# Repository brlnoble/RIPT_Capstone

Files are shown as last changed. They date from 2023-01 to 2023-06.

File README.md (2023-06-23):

# R.I.P.T. Capstone Project
This is a final year engineering capstone project for McMaster University. Students were given 8 months to develop a project and then present to judges and supervisors.

🏅3rd place for Most Impressive Prototype.

___

## About the Project
The **Robot Integrated Pad Trainer** (R.I.P.T.) is a device for helping boxers develop their offensive skills. The project uses a YOLOv7 computer vision model to observe and track the user with webcams, and identifies deficiencies in their skills. Once a training regime has been developed by a custom algorithm, pad training sessions can be conducted with the new regime. A gantry like system moves pads around for the user to interact with, sensing when they are hit before moving to a new location. This robotic emulation of a human pad trainer allows for more direct customization in the training, and is expandable and repeatable for any number of users and skill levels.

This project is a collaboration between Brandon Noble ([brlnoble](https://github.com/brlnoble "Brandon's Github")), Labib Kazi ([kazia3](https://github.com/kazia3 "Labib's Github")), Jame Tran ([JameTran](https://github.com/JameTran "Jame's Github")), and Hunter Ceranic ([cer-hunter](https://github.com/cer-hunter "Hunter's Github")).

### Explanation and Demonstration
View the explanation on YouTube <a href="https://youtu.be/TRa0bQ9WmGY" target="_blank" rel="noopener noreferrer">here</a>

View the demonstration on YouTube <a href="https://youtu.be/QMfrOVIuLZo" target="_blank" rel="noopener noreferrer">here</a>

___

## Project Goals
- [X] Robotic system to control boxing training pads
  - [X] H-bot inspired pulley system with 10mm GT2 belt, and custom mounts
  - [X] Zero motor position
  - [X] Fine motor control for NEMA 24 stepper motors to accurately move gantry system to specific locations
- [X] System to change pad orientation along 2 axes
  - [X] Mechanical design to support pad
  - [X] Control over position for different types of punches
- [X] YOLOv7 computer vision model
  - [X] Train YOLOv7 tiny model to recognize faces and boxing gloves
  - [X] Deploy on NVIDIA Jetson Nano
  - [X] Determine user blocking with intersection between gloves and face
- [X] Display and collect user metrics
  - [X] Implement various sensors to collect user metrics (i.e. reaction time, speed, endurance, accuracy, etc.)
  - [X] Web application to display metrics and training sessions
  - [X] Utilize user metrics to personalize a training regime
  
___

## Current State
The project is completed and almost all of the original goals have been met. Below are some pictures and GIFs of the device in operation.

#### Operation of the Device



#### 3D Model of the Future of RIPT
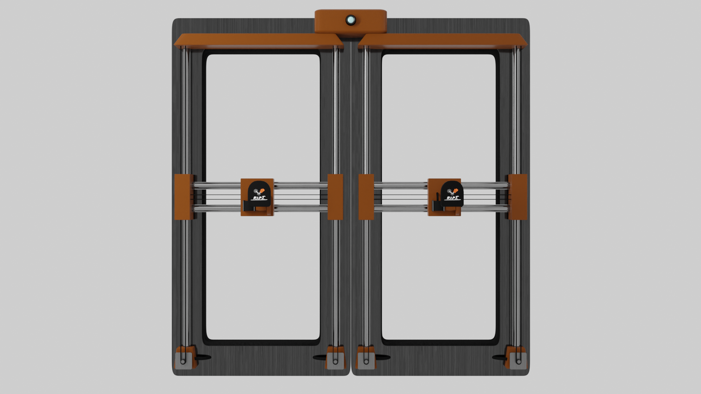
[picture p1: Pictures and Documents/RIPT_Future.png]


### Front End Demonstration of the Web App
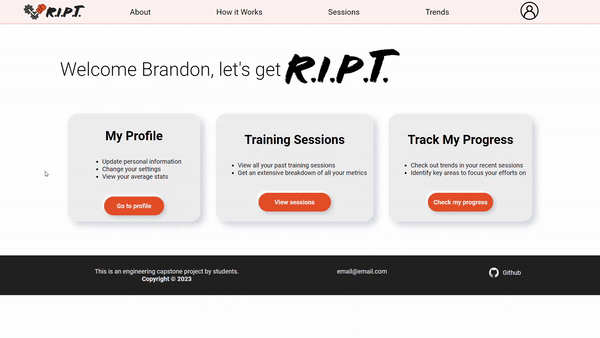
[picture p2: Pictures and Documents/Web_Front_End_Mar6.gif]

You can view a function version of the website at https://brlnoble.github.io/RIPT_Capstone/

#### Demonstration of the YOLOv7 Model
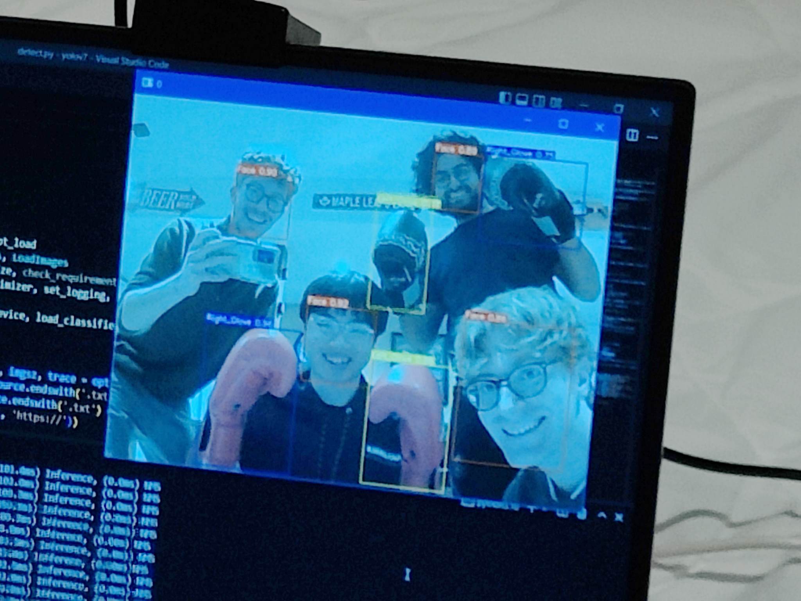
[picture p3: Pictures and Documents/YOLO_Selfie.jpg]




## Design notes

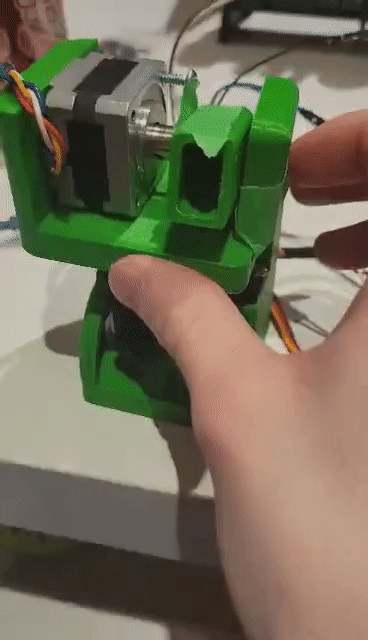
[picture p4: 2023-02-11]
Pictures and Documents/Pad_Orient_1.gif

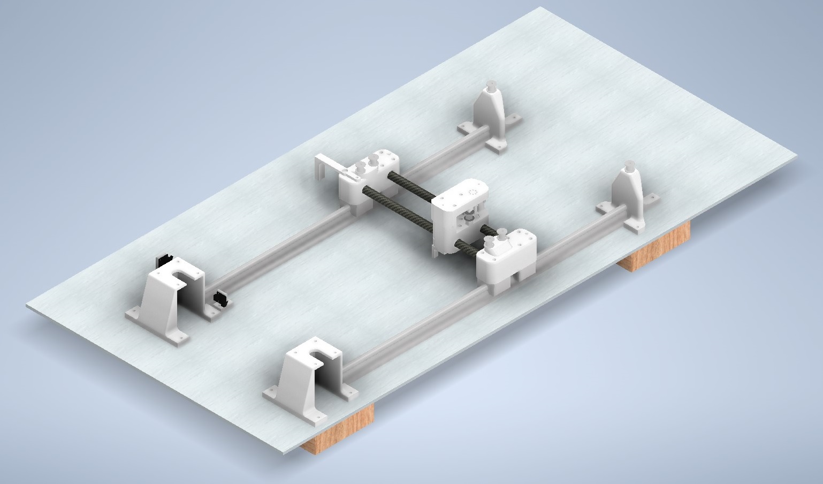
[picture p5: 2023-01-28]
Pictures and Documents/One_Side_Model.jpg

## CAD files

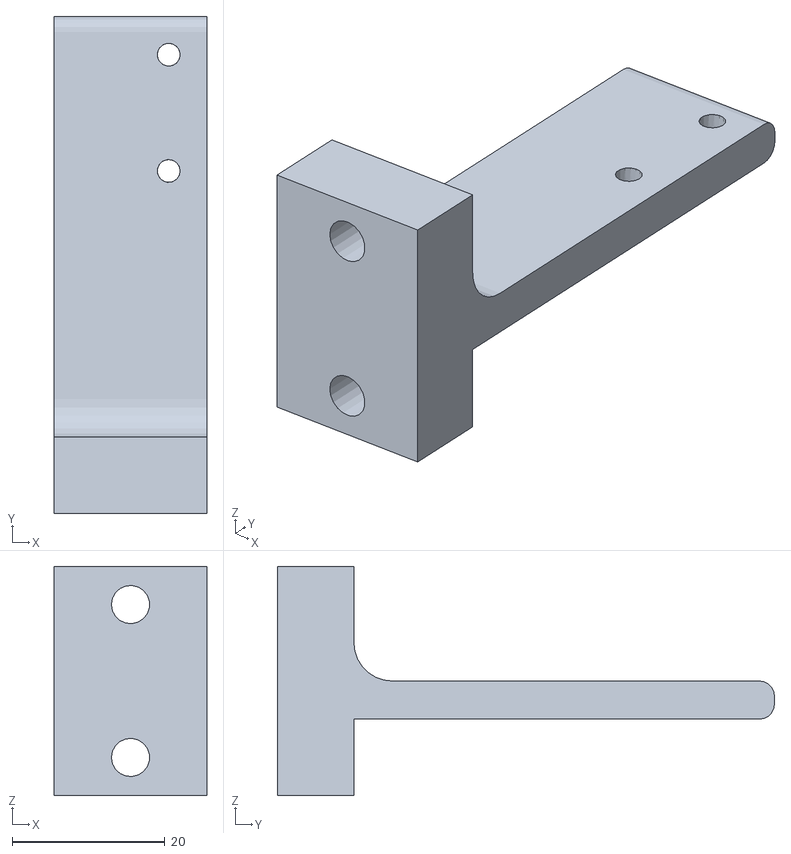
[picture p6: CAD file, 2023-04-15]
CAD Designs/Zero - Y Switch.stl
20.0 x 65.0 x 30.0

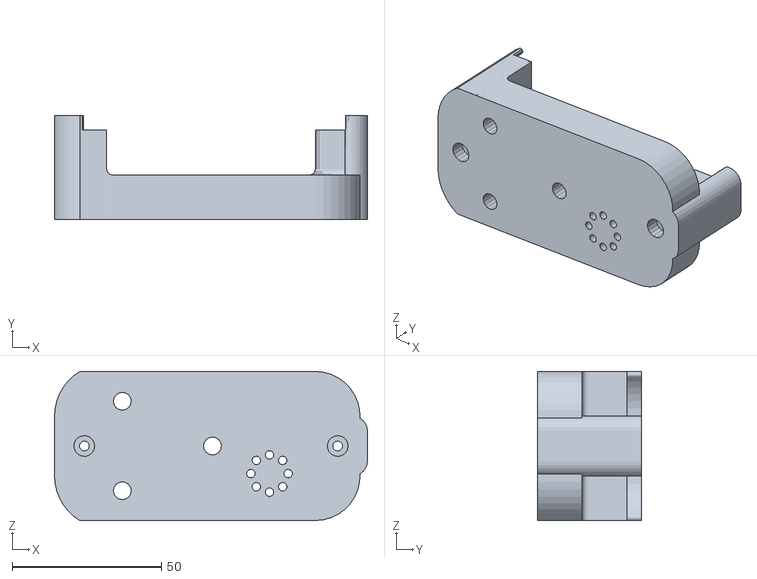
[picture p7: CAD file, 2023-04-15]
CAD Designs/Slider - Top.stl
105.0 x 35.0 x 50.0

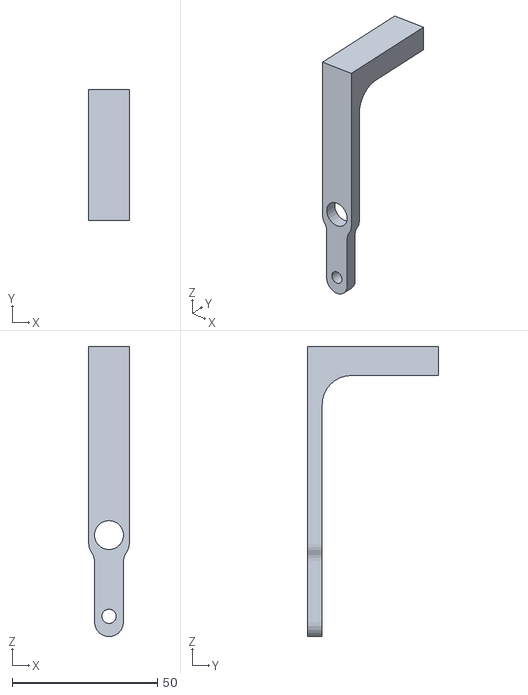
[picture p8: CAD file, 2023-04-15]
CAD Designs/Zero - Y Bracket.stl
14.0 x 45.0 x 99.9

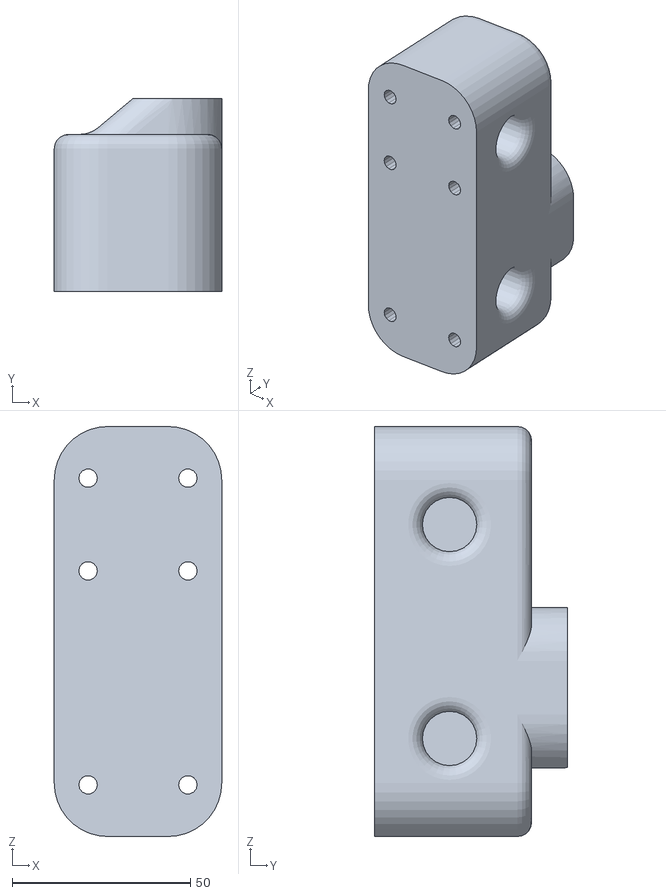
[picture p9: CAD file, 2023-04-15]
CAD Designs/Carbon Rod Mount R.stl
47.0 x 54.0 x 115.0

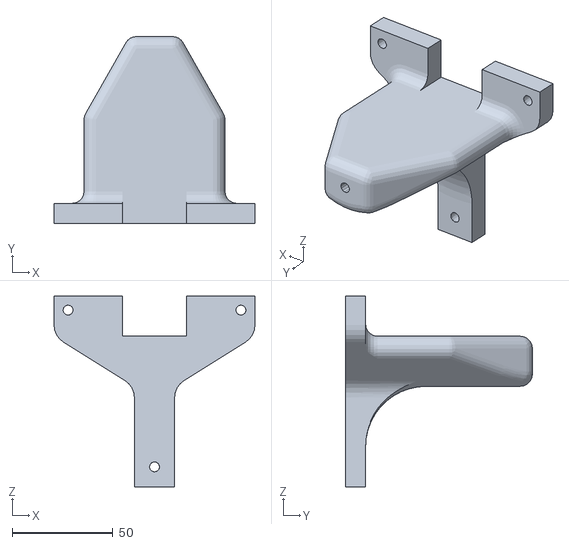
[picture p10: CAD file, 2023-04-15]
CAD Designs/Idler Mount.stl
100.0 x 93.0 x 95.0

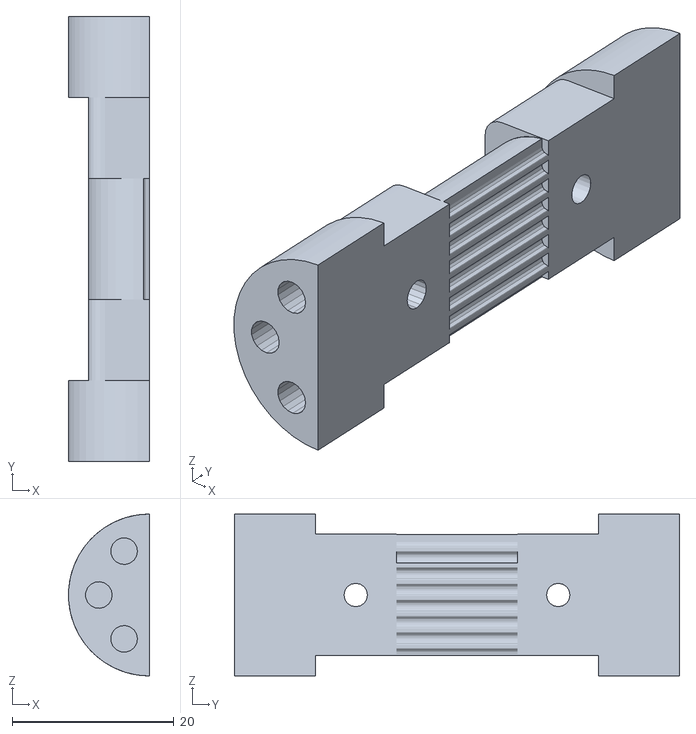
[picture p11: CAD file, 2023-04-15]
CAD Designs/Spool - Toothed Circle 2.stl
9.98 x 55.0 x 20.0

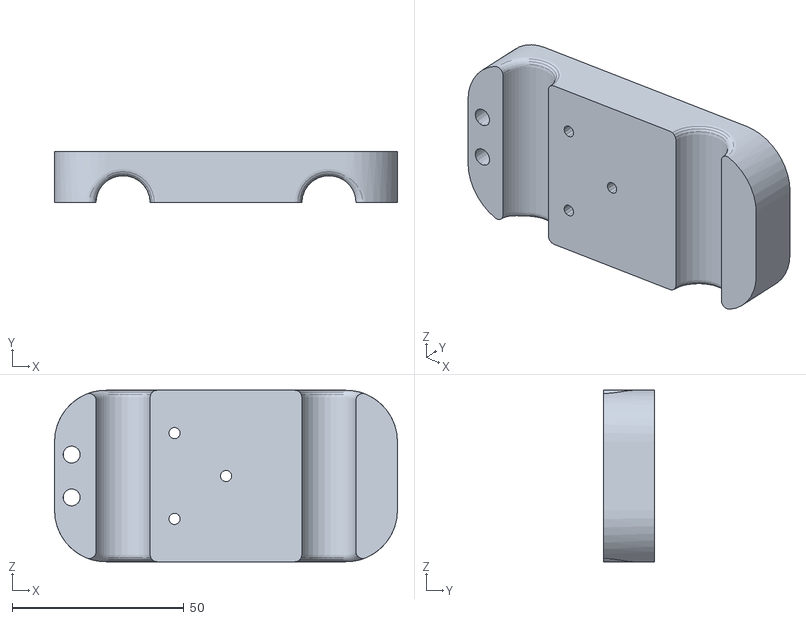
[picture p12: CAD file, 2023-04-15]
CAD Designs/Slider - Bottom.stl
100.0 x 15.0 x 50.0

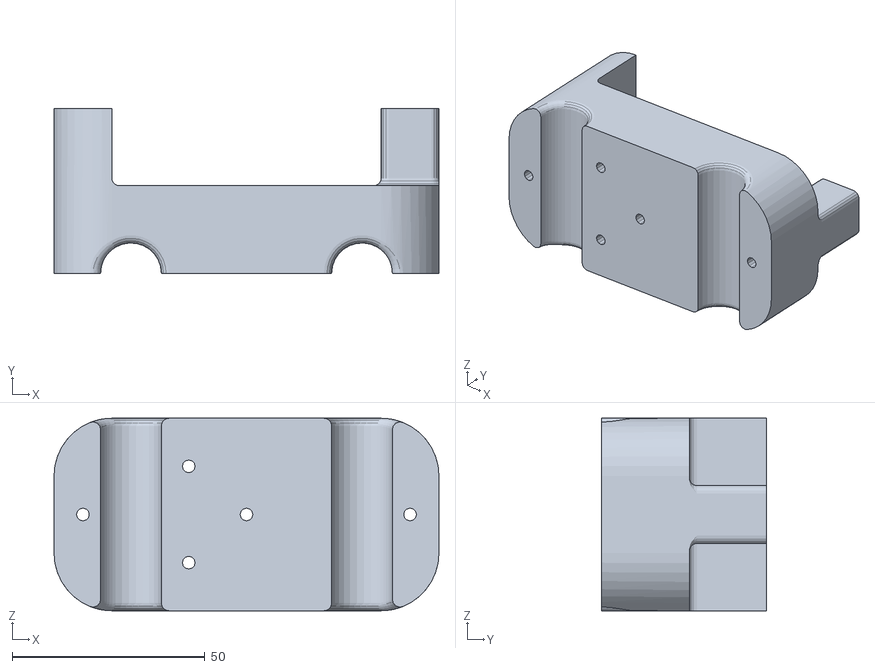
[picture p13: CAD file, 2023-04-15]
CAD Designs/Slider - Centre.stl
100.0 x 42.8 x 50.0

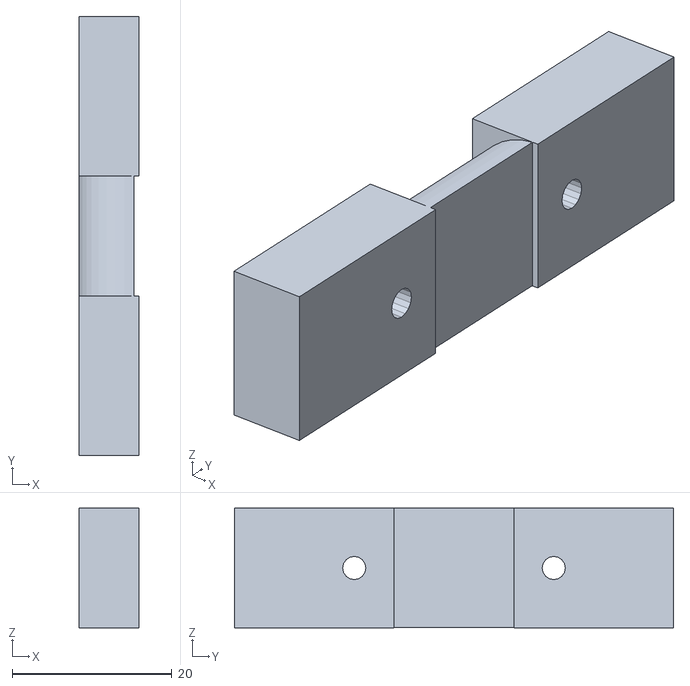
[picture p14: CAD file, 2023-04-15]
CAD Designs/Spool - Flat Square 2.stl
7.50 x 55.0 x 15.0

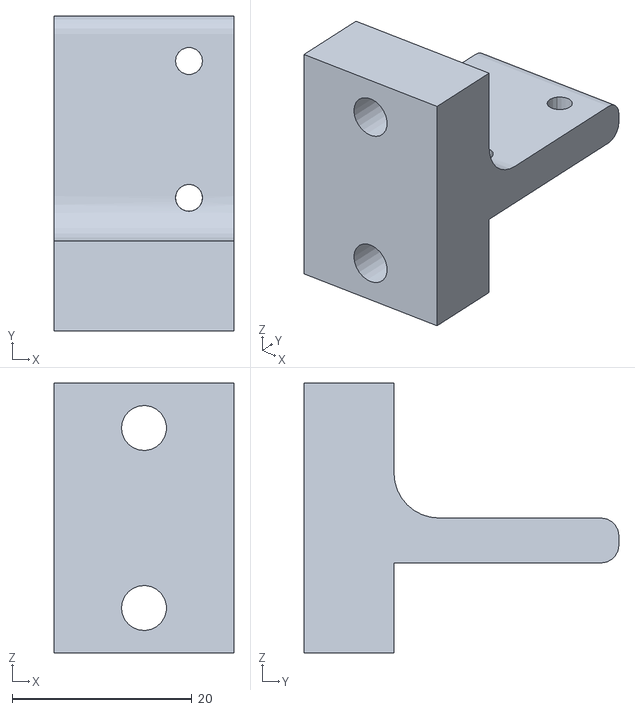
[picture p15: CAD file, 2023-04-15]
CAD Designs/Zero - X Switch.stl
20.0 x 35.0 x 30.0

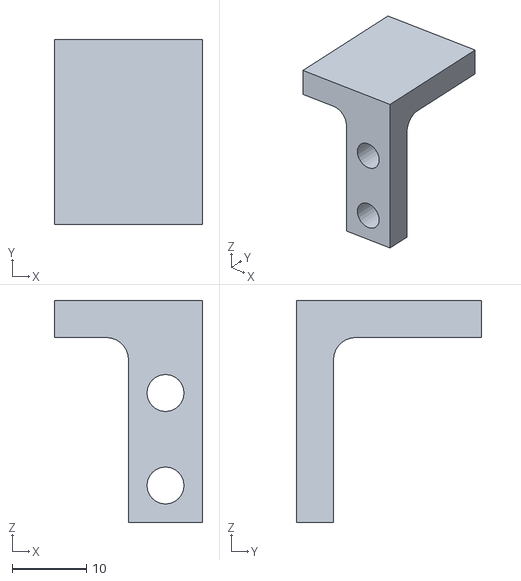
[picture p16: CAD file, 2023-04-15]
CAD Designs/Zero - X Bracket.stl
20.0 x 25.0 x 30.0

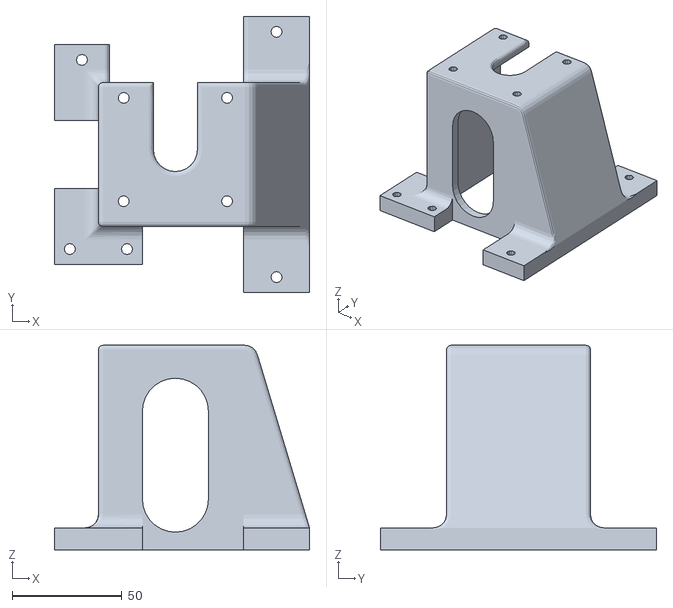
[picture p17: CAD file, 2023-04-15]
CAD Designs/Nema Mount.stl
116.0 x 125.5 x 93.0

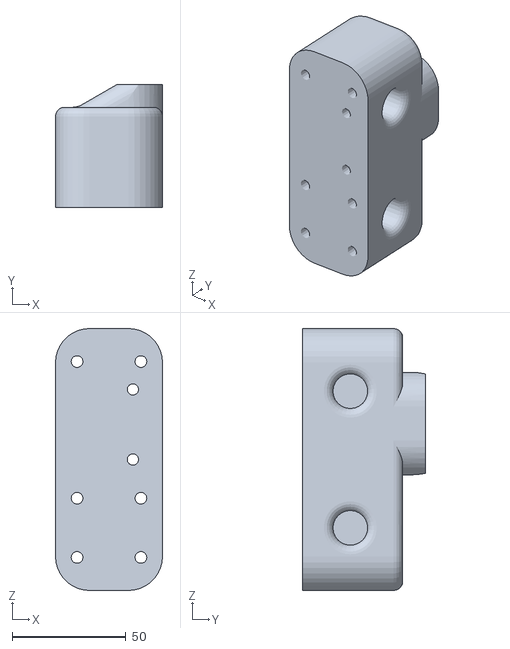
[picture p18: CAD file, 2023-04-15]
CAD Designs/Carbon Rod Mount L.stl
47.0 x 54.0 x 115.0

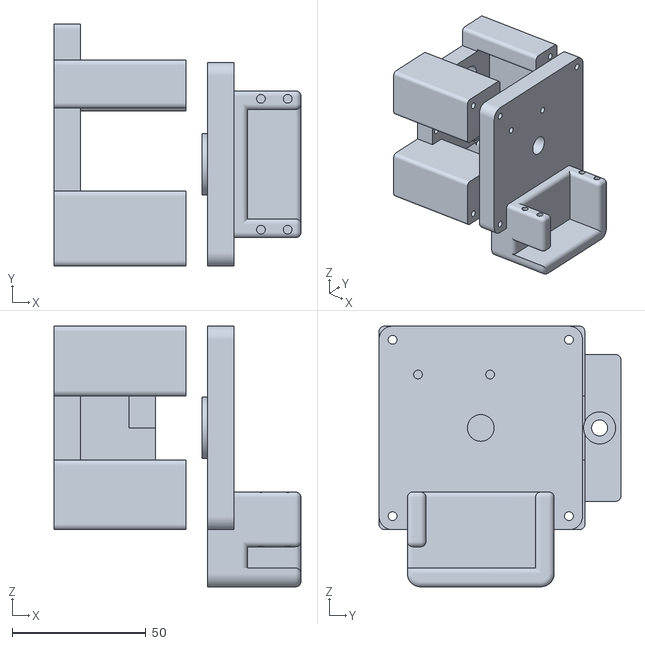
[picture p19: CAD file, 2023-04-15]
CAD Designs/padmount_doubleservo.stl
92.5 x 90.6 x 97.6

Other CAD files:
CAD Designs/Spool - Flat Circle 2.stl
CAD Designs/Spool - Toothed Square.stl
CAD Designs/finger.stl
CAD Designs/separator_plate_alternate.stl
CAD Designs/Slider Top 2.stl
CAD Designs/finger.ipt
CAD Designs/padmount_doubleservo.iam
CAD Designs/separator_plate_alternate.ipt
CAD Designs/servo_horz_plate.ipt
CAD Designs/servo_horz_plate.stl
CAD Designs/servo_pressfit_plate.ipt
CAD Designs/servo_pressfit_plate.stl
CAD Designs/stick_mount.ipt
CAD Designs/stick_mount.stl

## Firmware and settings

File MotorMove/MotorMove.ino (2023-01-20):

// Define stepper motor connections:
#define dirPin1 2
#define stepPin1 3

#define dirPin2 6
#define stepPin2 11

// Define limit switches
#define xLimit 9
#define yLimit 10


void setup() {
  pinMode(stepPin1, OUTPUT);
  pinMode(dirPin1, OUTPUT);

  pinMode(stepPin2, OUTPUT);
  pinMode(dirPin2, OUTPUT);
}

// ~~~~~~~~~~~~~~~~~~~~~~~~~~~~~~~~~~~~~~~~~~~~~
// ~~~~~~~~~~~~~~~~~~~~~~~~~~~~~~~~~~~~~~~~~~~~~
// ~~~~~~~~~~~~~~~~~~~~~~~~~~~~~~~~~~~~~~~~~~~~~
// ~~~~~~~~~~~~~~~~~~~~~~~~~~~~~~~~~~~~~~~~~~~~~

bool run = true;

//loop currently contains test code to find max frequency
void loop() {
  // put your main code here, to run repeatedly:
  if(run) {
    int numStepsX = 500;
    int numStepsY = 2000;
    int microdel = 230;
    int del = 40;
    digitalWrite(dirPin1,1);
    digitalWrite(dirPin2,0);

    for(int i=0;i<numStepsY;i++) {
      digitalWrite(stepPin1, HIGH);
      digitalWrite(stepPin2, HIGH);
      delayMicroseconds(microdel);
      digitalWrite(stepPin1, LOW);
      digitalWrite(stepPin2, LOW);
      delayMicroseconds(microdel);
    }

    delay(del);

    digitalWrite(dirPin1,1);
    digitalWrite(dirPin2,1);

    for(int i=0;i<numStepsX;i++) {
      digitalWrite(stepPin1, HIGH);
      digitalWrite(stepPin2, HIGH);
      delayMicroseconds(microdel);
      digitalWrite(stepPin1, LOW);
      digitalWrite(stepPin2, LOW);
      delayMicroseconds(microdel);
    }

    delay(del);

    digitalWrite(dirPin1,0);
    digitalWrite(dirPin2,1);

    for(int i=0;i<numStepsY;i++) {
      digitalWrite(stepPin1, HIGH);
      digitalWrite(stepPin2, HIGH);
      delayMicroseconds(microdel);
      digitalWrite(stepPin1, LOW);
      digitalWrite(stepPin2, LOW);
      delayMicroseconds(microdel);
    }

    delay(del);

    digitalWrite(dirPin1,0);
    digitalWrite(dirPin2,0);

    for(int i=0;i<numStepsX;i++) {
      digitalWrite(stepPin1, HIGH);
      digitalWrite(stepPin2, HIGH);
      delayMicroseconds(microdel);
      digitalWrite(stepPin1, LOW);
      digitalWrite(stepPin2, LOW);
      delayMicroseconds(microdel);
    }
    
    delay(del);
    run = false;
  }
  
}
// ~~~~~~~~~~~~~~~~~~~~~~~~~~~~~~~~~~~~~~~~~~~~~
// ~~~~~~~~~~~~~~~~~~~~~~~~~~~~~~~~~~~~~~~~~~~~~
// ~~~~~~~~~~~~~~~~~~~~~~~~~~~~~~~~~~~~~~~~~~~~~
// ~~~~~~~~~~~~~~~~~~~~~~~~~~~~~~~~~~~~~~~~~~~~~

// ~~~~~ Converts cm to motor steps ~~~~~
int distToStep(float cm) {
  return int(cm*0.009);
}

// ~~~~~~~~~~~~~~~~~~~~~~~~~~~~~~~~~~~~~~~~~~~~~
// ~~~~~~~~~~~~~~~~~~~~~~~~~~~~~~~~~~~~~~~~~~~~~
// ~~~~~ Move Y ~~~~~
void moveY(float currPos, float newPos) {
  float vector = currPos - newPos; //Calculates Y vector

  //Specifies up or down
  int direction = ( abs(vector) - vector) / abs(2*vector);
  digitalWrite(dirPin1, direction);
  digitalWrite(dirPin2, ~direction);

  //Move the device
  int numSteps = distToStep(vector);
  for(int i=0;i<numSteps;i++) {
    digitalWrite(stepPin1, HIGH);
    digitalWrite(stepPin2, HIGH);
    delayMicroseconds(50);
    digitalWrite(stepPin1, LOW);
    digitalWrite(stepPin2, LOW);
    delayMicroseconds(50);
  }
}

// ~~~~~~~~~~~~~~~~~~~~~~~~~~~~~~~~~~~~~~~~~~~~~
// ~~~~~~~~~~~~~~~~~~~~~~~~~~~~~~~~~~~~~~~~~~~~~
// ~~~~~ Move X ~~~~~
void moveX(float currPos, float newPos) {
  float vector = currPos - newPos; //Calculates Y vector

  //Specifies left or right
  int direction = ( abs(vector) - vector) / abs(2*vector);
  digitalWrite(dirPin1, direction);
  digitalWrite(dirPin2, direction);

  //Move the device
  int numSteps = distToStep(vector);
  for(int i=0;i<numSteps;i++) {
    digitalWrite(stepPin1, HIGH);
    digitalWrite(stepPin2, HIGH);
    delayMicroseconds(50);
    digitalWrite(stepPin1, LOW);
    digitalWrite(stepPin2, LOW);
    delayMicroseconds(50);
  }
}


// ~~~~~~~~~~~~~~~~~~~~~~~~~~~~~~~~~~~~~~~~~~~~~
// ~~~~~~~~~~~~~~~~~~~~~~~~~~~~~~~~~~~~~~~~~~~~~
// ~~~~~ Zero the unit ~~~~~
void goToZero() {
  //Move slightly down first
  digitalWrite(dirPin1, 0);
  digitalWrite(dirPin2, 1);

  for(int i=0;i<100;i++) {
    digitalWrite(stepPin1, HIGH);
    digitalWrite(stepPin2, HIGH);
    delayMicroseconds(50);
    digitalWrite(stepPin1, LOW);
    digitalWrite(stepPin2, LOW);
    delayMicroseconds(50);
  }

  //Move slightly to the right
  digitalWrite(dirPin1, 0);
  digitalWrite(dirPin2, 0);

  for(int i=0;i<100;i++) {
    digitalWrite(stepPin1, HIGH);
    digitalWrite(stepPin2, HIGH);
    delayMicroseconds(50);
    digitalWrite(stepPin1, LOW);
    digitalWrite(stepPin2, LOW);
    delayMicroseconds(50);
  }

  //Move Y until it hits the switch
  digitalWrite(dirPin1, 1);
  digitalWrite(dirPin2, 0);

  while(digitalRead(yLimit) == 0) {
    digitalWrite(stepPin1, HIGH);
    digitalWrite(stepPin2, HIGH);
    delayMicroseconds(200);
    digitalWrite(stepPin1, LOW);
    digitalWrite(stepPin2, LOW);
    delayMicroseconds(200);    
  }

  //Move X until it hits the switch
  digitalWrite(dirPin1, 1);
  digitalWrite(dirPin2, 1);

  while(digitalRead(xLimit) == 0) {
    digitalWrite(stepPin1, HIGH);
    digitalWrite(stepPin2, HIGH);
    delayMicroseconds(200);
    digitalWrite(stepPin1, LOW);
    digitalWrite(stepPin2, LOW);
    delayMicroseconds(200);    
  }

  //Move slightly down
  digitalWrite(dirPin1, 0);
  digitalWrite(dirPin2, 1);

  for(int i=0;i<100;i++) {
    digitalWrite(stepPin1, HIGH);
    digitalWrite(stepPin2, HIGH);
    delayMicroseconds(500);
    digitalWrite(stepPin1, LOW);
    digitalWrite(stepPin2, LOW);
    delayMicroseconds(500);
  }

  //Move slightly to the right
  digitalWrite(dirPin1, 0);
  digitalWrite(dirPin2, 0);

  for(int i=0;i<100;i++) {
    digitalWrite(stepPin1, HIGH);
    digitalWrite(stepPin2, HIGH);
    delayMicroseconds(500);
    digitalWrite(stepPin1, LOW);
    digitalWrite(stepPin2, LOW);
    delayMicroseconds(500);
  }

  //Move up really slowly same distance as it was moved down in the last step
  digitalWrite(dirPin1, 1);
  digitalWrite(dirPin2, 0);

  for(int i=0;i<100;i++) {
    digitalWrite(stepPin1, HIGH);
    digitalWrite(stepPin2, HIGH);
    delayMicroseconds(500);
    digitalWrite(stepPin1, LOW);
    digitalWrite(stepPin2, LOW);
    delayMicroseconds(500);
  }

  //Move left really slowly same distance as it was moved right in the last step
  digitalWrite(dirPin1, 1);
  digitalWrite(dirPin2, 1);

  for(int i=0;i<100;i++) {
    digitalWrite(stepPin1, HIGH);
    digitalWrite(stepPin2, HIGH);
    delayMicroseconds(500);
    digitalWrite(stepPin1, LOW);
    digitalWrite(stepPin2, LOW);
    delayMicroseconds(500);
  }

  //restart calibration if the pad is not zeroed
  if(digitalRead(yLimit) == 0 || digitalRead(xLimit) == 0){
    goToZero();
  }
}

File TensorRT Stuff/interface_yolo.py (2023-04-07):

"""
An example that uses TensorRT's Python api to make inferences.
"""
import ctypes
import os
import shutil
import random
import sys
import threading
import time
import cv2
import numpy as np
import pycuda.autoinit
import pycuda.driver as cuda
import tensorrt as trt

#ADDED
import PySimpleGUI as sg
import sgInterface
import RPi.GPIO as GPIO
from time import perf_counter,sleep

from form_send import Client

CONF_THRESH = 0.5
IOU_THRESHOLD = 0.4


def get_img_path_batches(batch_size, img_dir):
    ret = []
    batch = []
    for root, dirs, files in os.walk(img_dir):
        for name in files:
            if len(batch) == batch_size:
                ret.append(batch)
                batch = []
            batch.append(os.path.join(root, name))
    if len(batch) > 0:
        ret.append(batch)
    return ret

def plot_one_box(x, img, color=None, label=None, line_thickness=None):
    """
    description: Plots one bounding box on image img,
                 this function comes from YoLov7 project.
    param: 
        x:      a box likes [x1,y1,x2,y2]
        img:    a opencv image object
        color:  color to draw rectangle, such as (0,255,0)
        label:  str
        line_thickness: int
    return:
        no return

    """
    tl = (
        line_thickness or round(0.002 * (img.shape[0] + img.shape[1]) / 2) + 1
    )  # line/font thickness
    color = [36,90,241] if label[0] == "F" else [241,133,36]
    #color = color or [random.randint(0, 255) for _ in range(3)]
    c1, c2 = (int(x[0]), int(x[1])), (int(x[2]), int(x[3]))
    cv2.rectangle(img, c1, c2, color, thickness=tl, lineType=cv2.LINE_AA)
    if label:
        tf = max(tl - 1, 1)  # font thickness
        t_size = cv2.getTextSize(label, 0, fontScale=tl / 3, thickness=tf)[0]
        c2 = c1[0] + t_size[0], c1[1] - t_size[1] - 3
        cv2.rectangle(img, c1, c2, color, -1, cv2.LINE_AA)  # filled
        cv2.putText(
            img,
            label,
            (c1[0], c1[1] - 2),
            0,
            tl / 3,
            [225, 255, 255],
            thickness=tf,
            lineType=cv2.LINE_AA,
        )


class YoLov7TRT(object):
    """
    description: A YOLOv7 class that warps TensorRT ops, preprocess and postprocess ops.
    """

    def __init__(self, engine_file_path):
        # Create a Context on this device,
        self.ctx = cuda.Device(0).make_context()
        stream = cuda.Stream()
        TRT_LOGGER = trt.Logger(trt.Logger.INFO)
        runtime = trt.Runtime(TRT_LOGGER)

        # Deserialize the engine from file
        with open(engine_file_path, "rb") as f:
            engine = runtime.deserialize_cuda_engine(f.read())
        context = engine.create_execution_context()

        host_inputs = []
        cuda_inputs = []
        host_outputs = []
        cuda_outputs = []
        bindings = []

        for binding in engine:
            print('bingding:', binding, engine.get_binding_shape(binding))
            size = trt.volume(engine.get_binding_shape(binding)) * engine.max_batch_size
            dtype = trt.nptype(engine.get_binding_dtype(binding))
            # Allocate host and device buffers
            host_mem = cuda.pagelocked_empty(size, dtype)
            cuda_mem = cuda.mem_alloc(host_mem.nbytes)
            # Append the device buffer to device bindings.
            bindings.append(int(cuda_mem))
            # Append to the appropriate list.
            if engine.binding_is_input(binding):
                self.input_w = engine.get_binding_shape(binding)[-1]
                self.input_h = engine.get_binding_shape(binding)[-2]
                host_inputs.append(host_mem)
                cuda_inputs.append(cuda_mem)
            else:
                host_outputs.append(host_mem)
                cuda_outputs.append(cuda_mem)

        # Store
        self.stream = stream
        self.context = context
        self.engine = engine
        self.host_inputs = host_inputs
        self.cuda_inputs = cuda_inputs
        self.host_outputs = host_outputs
        self.cuda_outputs = cuda_outputs
        self.bindings = bindings
        self.batch_size = engine.max_batch_size

    def infer_warmup(self, raw_image_generator):
        threading.Thread.__init__(self)
        # Make self the active context, pushing it on top of the context stack.
        self.ctx.push()
        # Restore
        stream = self.stream
        context = self.context
        engine = self.engine
        host_inputs = self.host_inputs
        cuda_inputs = self.cuda_inputs
        host_outputs = self.host_outputs
        cuda_outputs = self.cuda_outputs
        bindings = self.bindings
        # Do image preprocess
        batch_image_raw = []
        batch_origin_h = []
        batch_origin_w = []
        batch_input_image = np.empty(shape=[self.batch_size, 3, self.input_h, self.input_w])
        for i, image_raw in enumerate(raw_image_generator):
            input_image, image_raw, origin_h, origin_w = self.preprocess_image(image_raw)
            batch_image_raw.append(image_raw)
            batch_origin_h.append(origin_h)
            batch_origin_w.append(origin_w)
            np.copyto(batch_input_image[i], input_image)
        batch_input_image = np.ascontiguousarray(batch_input_image)

        # Copy input image to host buffer
        np.copyto(host_inputs[0], batch_input_image.ravel())
        start = time.time()
        # Transfer input data  to the GPU.
        cuda.memcpy_htod_async(cuda_inputs[0], host_inputs[0], stream)
        # Run inference.
        context.execute_async(batch_size=self.batch_size, bindings=bindings, stream_handle=stream.handle)
        # Transfer predictions back from the GPU.
        cuda.memcpy_dtoh_async(host_outputs[0], cuda_outputs[0], stream)
        # Synchronize the stream
        stream.synchronize()
        end = time.time()
        # Remove any context from the top of the context stack, deactivating it.
        self.ctx.pop()
        # Here we use the first row of output in that batch_size = 1
        output = host_outputs[0]
        # Do postprocess
        for i in range(self.batch_size):
            result_boxes, result_scores, result_classid = self.post_process(
                output[i * 6001: (i + 1) * 6001], batch_origin_h[i], batch_origin_w[i]
            )
            # Draw rectangles and labels on the original image
            for j in range(len(result_boxes)):
                box = result_boxes[j]
                plot_one_box(
                    box,
                    batch_image_raw[i],
                    label="{}:{:.2f}".format(
                        categories[int(result_classid[j])], result_scores[j]
                    ),
                )
        return batch_image_raw, end - start
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

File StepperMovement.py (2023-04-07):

import RPi.GPIO as GPIO #for IO control
import ServoMovement
from time import sleep, perf_counter
from multiprocessing import Process, Queue

#Define clockwise and counter clockwise for readability
cw = GPIO.HIGH
ccw = GPIO.LOW

class Stepper:
    def __init__(self,motorPins,zeroPins,loadPins,servoPins,servoAngs,jetPin):

        #Pins for the motor drivers
        self.dirPin1 = motorPins[0]
        self.dirPin2 = motorPins[1]
        self.stepPin1 = motorPins[2]
        self.stepPin2 = motorPins[3]

        #Pins for the zero positioning
        self.zeroPinX = zeroPins[0]
        self.zeroPinY = zeroPins[1]

        #Pins for clock and reading values of the load cell
        #self.loadRead = loadPins[0]
        #self.loadClock = loadPins[1]
        #self.loadCalibrate = 0 #value for calibration
        
        #Pin for Jetson communication
        self.jetPin = jetPin
        
        #For the pad movement
        GPIO.setmode(GPIO.BCM)
        self.servos = ServoMovement.RIPT_Servo(servoPins,servoAngs[0],servoAngs[1],servoAngs[2])

        #Parameters of the motors
        self.speed_max_default =  150e3 #delay between pulses (200k Hz default)
        self.speed_min_default = 75e3
        self.m_delay = 0.25 #delay between movements
        self.m_steps = 1600 #steps per rotation (1/8 microstep)
        self.m_diameter = 1.215 #diameter of the motor gear in cm

        #Location tracking
        self.location = [0,0]

        #Time the user has to punch the target
        self.punch_timer = 3.0

        #Setup the GPIO pins
        GPIO.setup(self.dirPin1,GPIO.OUT)
        GPIO.setup(self.stepPin1,GPIO.OUT)
        GPIO.setup(self.dirPin2,GPIO.OUT)
        GPIO.setup(self.stepPin2,GPIO.OUT)
        GPIO.setup(self.jetPin,GPIO.OUT)

        GPIO.setup(self.zeroPinX,GPIO.IN)
        GPIO.setup(self.zeroPinY,GPIO.OUT)

        #GPIO.setup(self.loadPin,GPIO.IN)

    #~~~~~ Return the parameters ~~~~~
    def __str__(self):
        return f"Motor Pins: {self.dirPin1},{self.dirPin2},{self.stepPin1},{self.stepPin2} \nZero Pins: {self.zeroPinX},{self.zeroPinY}"

    #~~~~~ Set the pins being used ~~~~~
    def Set_Pins(self,pins):
        self.dirPin1,self.dirPin2,self.stepPin1,self.stepPin2 = pins

    #~~~~~ Convert cm to steps ~~~~~
    def Dist_to_Steps(self,distance):
        return int( (distance / (3.14156 * self.m_diameter)) * self.m_steps) #return the number of steps as an integer

    #~~~~~ Convert steps to cm ~~~~~
    def Steps_to_Dist(self,steps):
        return (steps / self.m_steps) * (3.14156 * self.m_diameter)
        
    #~~~~~ Move motors a given number of steps ~~~~~
    def Move_Motors(self,steps,speed_max,speed_min):    
        #Accelerate over two rotation if steps and max/min speeds set
        if steps > 3200 and speed_max != speed_min:
            
            accel_step = (speed_max - speed_min)/3200 #Frequency increase per step
            
            for accel in range(0,3200):
                
                accel_speed = 1 / (accel_step*accel + speed_min) #New speed
                
                GPIO.output(self.stepPin1,GPIO.HIGH)
                GPIO.output(self.stepPin2,GPIO.HIGH)
                sleep(accel_speed)
                GPIO.output(self.stepPin1,GPIO.LOW)
                GPIO.output(self.stepPin2,GPIO.LOW)
                sleep(accel_speed)
                
            #Correct steps and speed for acceleration        
            steps -= 3200
            speed = 1 / speed_max #convert frequency to seconds

        #Move at minimum speed otherwise
        else:
            speed = 1 / speed_min #convert frequency to seconds
        
        #Move the motor in the specified direction for the specified number of steps
        for step in range(steps):
            GPIO.output(self.stepPin1,GPIO.HIGH)
            GPIO.output(self.stepPin2,GPIO.HIGH)
            sleep(speed)
            GPIO.output(self.stepPin1,GPIO.LOW)
            GPIO.output(self.stepPin2,GPIO.LOW)
            sleep(speed)

    #~~~~~ Change motor direction ~~~~~
    def Motor_Direction(self,direction):
        #Change motor direction as specified
        if direction == "up":
            GPIO.output(self.dirPin1,ccw)
            GPIO.output(self.dirPin2,cw)
        elif direction == "down":
            GPIO.output(self.dirPin1,cw)
            GPIO.output(self.dirPin2,ccw)
        elif direction == "left":
            GPIO.output(self.dirPin1,ccw)
            GPIO.output(self.dirPin2,ccw)
        elif direction == "right":
            GPIO.output(self.dirPin1,cw)
            GPIO.output(self.dirPin2,cw)
        return        

    #~~~~~ Movement based on direction and distance ~~~~~
    def Move_Distance(self,direction,distance):
        #Change motor direction as specified
        self.Motor_Direction(direction)

        steps_to_move = self.Dist_to_Steps(distance) #number of steps to move
        dist_to_move = self.Steps_to_Dist(steps_to_move) #actual distance moved after rounding
        dist_to_move = distance

        #Calculate new position
        if direction == "up":
            self.location[1] += dist_to_move
            
            #Set the speed for movement
            speed_max = self.speed_max_default
            speed_min = self.speed_min_default
            
        elif direction == "down":
            self.location[1] -= dist_to_move
            
            #Set the speed for movement
            speed_max = self.speed_max_default
            speed_min = self.speed_min_default
            
        elif direction == "left":
            self.location[0] -= dist_to_move
            
            #Set the speed for movement
            speed_max = self.speed_max_default/2
            speed_min = self.speed_min_default/2
            
        elif direction == "right":
            self.location[0] += dist_to_move
            
            #Set the speed for movement
            speed_max = self.speed_max_default/2
            speed_min = self.speed_min_default/2

        #Move the motors into position
        if distance != 0:
            self.Move_Motors(steps_to_move,speed_max,speed_min)

    #Move to a specific position
    def Move_To(self,x_move,y_move):
        #Make sure values are valid first
        if x_move <= 12.0 and x_move >= 0.0 and y_move <= 45.0 and y_move >= 0.0:
            
            #Calculate relative movements to get into position
            x_move = x_move - self.location[0]
            y_move = y_move - self.location[1]
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

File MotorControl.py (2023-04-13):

'''
This will be the main file for which the R-Pi runs all the motor control code from

The two boards will be operated in parallel with both the gantry and pad control
'''

import RPi.GPIO as GPIO
from time import sleep
from multiprocessing import Process, Queue
import json

import punch
import StepperMovement
import ServoMovement

#~~~~~ Setup the left stepper motors ~~~~~
leftPins = [
    3, #dir1
    17, #dir2
    2, #step1
    4 #step2
]

leftZero = [
    14, #X zero
    15 #Y zero
]

leftServoPins = [
    6, #top
    13 #bot
]

leftServoAngs = [
    [160,0],
    [120,90],
    [90,0]
]

#Pin for communicating with the Jetson
leftJet = 22

boardLeft = StepperMovement.Stepper(leftPins,leftZero,[11,9],leftServoPins,leftServoAngs,leftJet) #can use the same clock for both load cells

#servosLeft = ServoMovement.RIPT_Servo(leftPins,leftServoAngs[0],

#~~~~~ Setup the right stepper motors ~~~~~
rightPins = [
    16, #dir1
    21, #dir2
    12, #step1
    20 #step2
]

rightZero = [
    19, #X zero
    26 #Y zero
]

rightServoPins = [
     23, #top
     24 #bot
]

rightServoAngs = [
     [75,90], #jab
     [160,90], #uppercut
     [120,0] #hook
]

#Pin for communicating with the Jetson
rightJet = 27

boardRight = StepperMovement.Stepper(rightPins,rightZero,[0,0],rightServoPins,rightServoAngs, rightJet) #can use the same clock for both load cells


#~~~~~ Get the punch sequences ~~~~~
numPunches = 5
punchSeqLeft = punch.Punch_Sequence(numPunches,["q1","q2"])
punchSeqRight = punch.Punch_Sequence(numPunches,["q3","q4"])

#~~~~~~~~~~~~~~~~~~~~~~~~~~~~~~~~~~~~~~~~~~~~~~~~~~~~~~~~~~~~~~~~~~~~~~~~~~~~~~~~~~~~~~~~~
#~~~~~~~~~~~~~~~~~~~~~~~~~~~~~~~~~~~~~~~~~~~~~~~~~~~~~~~~~~~~~~~~~~~~~~~~~~~~~~~~~~~~~~~~~
#~~~~~~~~~~~~~~~~~~~~~~~~~~~~~~~~~~~~~~~~~~~~~~~~~~~~~~~~~~~~~~~~~~~~~~~~~~~~~~~~~~~~~~~~~
#~~~~~~~~~~~~~~~~~~~~~~~~~~~~~~~~~~~~~~~~~~~~~~~~~~~~~~~~~~~~~~~~~~~~~~~~~~~~~~~~~~~~~~~~~
#~~~~~~~~~~~~~~~~~~~~~~~~~~~~~~~~~~~~~~~~~~~~~~~~~~~~~~~~~~~~~~~~~~~~~~~~~~~~~~~~~~~~~~~~~
jetson_in = 10
GPIO.setup(jetson_in,GPIO.IN)

jet_state = 0

try:
    while True:
        jet_read = GPIO.input(jetson_in)
        
        if jet_read != jet_state:
                

            #~~~~~ Zero the motors ~~~~~
            print("~~~~~ Zeroing motors ~~~~~")
            thread1 = Process(target=boardRight.Zero_Motors, args=())
            thread2 = Process(target=boardLeft.Zero_Motors, args=())
            threads = [thread1, thread2]

            #Start threads
            for thread in threads:
                thread.start()

            #Join so the threads so we ensure both finish before continuing
            for thread in threads:
                thread.join()

            #~~~~~ Loop through the punches ~~~~~
            endTime = 30.0 #maximum runtime of the program (30s)

            while GPIO.input(jetson_in) == GPIO.LOW:
                sleep(0)

            sleep(3)
            print("~~~~~ Starting movements ~~~~~")

            #Using queues to return the punch objects to the main program
            results = Queue()
            results = Queue()

            #Create the movement threads
            thread1 = Process(target=boardLeft.Movements, args=(punchSeqLeft,endTime,results))
            thread2 = Process(target=boardRight.Movements, args=(punchSeqRight,endTime,results))
            threads = [thread1, thread2]

            for thread in threads:
                thread.start()

            for thread in threads:
                thread.join()

            #~~~~~ Save the results ~~~~~

            writeData = []
            for i in range(results.qsize()):
                p = results.get()
                writeData.append(p.Return_Data())

            writeData = json.dumps(writeData) #Convert to json

            with open("results.json","w") as f:
                f.write(writeData)

            
            jet_state = 0
            print("Session finished")

except KeyboardInterrupt:

    del boardLeft
    del boardRight
    GPIO.cleanup()

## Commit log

2023-01-05 Rough outline of the motor code
    Just setting up the required functions and basic functionality. Needs to generate coordinates and be tested.
2023-01-21 Python code for motor movement
    Sample code to test in the coming weeks on the Jetson Nano as we migrate off of the Arduino platform
2023-01-23 Simple interface for the MotorMove.py file
    Moves the MotorMove.py file into a function, and adds an interface to change the steps and delays. Make sure to change lines 9-13 to make sure the pins are correct.
    [simple_interface.py]
2023-01-27 Interface for simple motor control
    This interface has up, down, left, right buttons. Holding a button will control the motors to move the H-Bot system in that direction.
2023-01-29 Program to test movement
    Simple program with interface to test movement. Takes a distance in centimetres and converts to steps before moving. Trying to see how accurate I can get it and minimize errors after rounding.
    [MotorMovementTest.py]
2023-01-29 Logic and calibration fix
    Fixing this program to have proper calculations. It is now calibrated to within 5% (i.e. 10cm input -> 10.05cm movement). Will conduct a more robust calibration later.
    [MotorMovementTest.py]
2023-01-29 Added support for specifying positions
    Can now specify an X and Y position to move to. Computes the movement relative to the current position.
    Still working on the zeroing function.
2023-01-29 Zero functionality now functioning
    The zeroing function now works. It moves up 2cm and then right 2cm first (in case it was already zeroed), and then moves at 1/100th the speed of normal operation. Moves 1 step at a time along each ax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
    Have yet to test with the mounted switches on the board, but implementation is there.
2023-02-11 Updated GIFs of the current progress.
2023-02-19 Acceleration added to movements
    If the movement is above a certain distance, the motors are accelerated from a minimum to a maximum speed over one rotation. This is to help prevent the motors from skipping sometimes as we have had issues with this. So far, the acceleration seems to have solved this with very minimal impact on the duration of movement. Max speed has also been increased from 100kHz to 200kHz (the maximum supported by the TB6600 drivers).
    [MotorMovementTest.py]
2023-02-20 Navbar for web app created
    Navbar has been created for the web app. Currently no functionality has been implemented.
2023-02-22 Initial commit.
    Initial commit of class for controlling the servo motors responsible for fine positioning of the pads.
2023-02-24 Progress on session screen
    Setup most of the components for the sessions screen. Still need to work on passing props all the way down, but for the most part it's functional.
2023-02-24 Separating data from components
    Successfully separated the data for a session from the components. This will allow the backend to pass this information to the session page and have it propagate through the props to the required com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
2023-02-24 Fixed buttons
    Fixed buttons so they properly integrate with react-dom-router Link.
2023-02-27 Rudimentary UI for the yolov7 model
    Super rough GUI for the TensorRT model. Has a startup screen, and another that shows the inference.
    I have to create the UI objects in the inference thread since TKinter cannot be run outside of main (see https://stackoverflow.com/a/45803955). To get around it I build the UI objects in the inference thread. TKinter still throws an error on exit, but by then the program has finished running so its "fine".
    Next steps is to make the UI more advanced and see if it has any affect on the inference times.
    [sgInterface.py]
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2023-03-07 Update Python code
    After testing ideal servo angles using arduino, updating python code to reflect this
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2023-03-08 Stepper class created
    Moved all the functionality of MotorMovementTest.py to a new class.
    This is still untested, but should help when the system requires parallel operation of the two boards side by side.
2023-03-08 Pivoting away from using a class to define the servos
2023-03-08 swapping to a more concise library
    [servo-test.py]
2023-03-09 Fixed the functions
    Incorrect whitespace rendered function inaccessible. Has now been fixed.
    [StepperMovement.py]
2023-03-12 Setting up motor control program
    Setting up the foundation for the motor control program on the R-Pi. Currently untested.
2023-03-12 Archiving
    No longer in use.
    [MotorMovementTest.py]
2023-03-14 Fixing motor angles for new set-up
    [servo-test.py]
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2023-03-15 Untested load cell code
    Followed the datasheet to create code for the HX711 load cell amplifier/ADC. I have yet to test it, but it should only require minor tweaking from here.
2023-03-15 Fixed typo in load cell code
    Had the for loop in range(25,-1,-1). Should be range(24,-1,-1) for channel A at gain of 128.
    [StepperMovement.py]
2023-03-15 Changed Jetson interface
    Updated the Jetson interface so only one window object is needed.
    Will significantly cut down on load time and allow the program to quickly change screens.
2023-03-16 Fixed errors in test
    Fixed a couple mistakes I made writing the previous commit.
    [MotorControl.py, StepperMovement.py]
2023-03-16 Movements moved to class
    The movement loops work in the new class function "Movements". This allows the punches to be passed as an array with the maximum duration.
    Next steps are to implement the Punch class along with this, and get the load cells reading correctly.
    [StepperMovement.py]
2023-03-16 Updating acceleration
    Motors occasionally skip, now accelerating over two rotations instead of one.
    [StepperMovement.py]
2023-03-17 Fixed function call
    Fixed function calls to use the new naming convention
    [MotorControl.py]
2023-03-17 Results now return to main thread
    The parallel processes moving the two boards collect metrics and return the results with "Queue" from "multiprocessing".
    This allows the metrics to be collected separately from the main thread before being analyzed and sent to the server.
2023-03-17 Results follow dynamic sizing
    In the event the movement thread reaches the time limit instead of the punch limit (completes 25/30 punches), the results will scale to match the number of punches that were completed.
2023-03-17 Removed second movement thread
    Movement cannot be done in another process since the multiprocessing library passes a copy of the object to the new process. This results in the "location" variable not being shared, so the main proc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
2023-03-17 Metric collection
    Punch class now has a function to return the class variables.
    Main MotorControl.py program writes the collected metrics from each board into resultsL.txt and resultsR.txt respectively.
2023-03-18 Updated vision file
    Updated interface for the Jetson display.
    @JameTran created a new engine file for the YOLO model
    [interface_yolo.py, sgInterface.py]
2023-03-18 Analysis of metrics with JSON
    Metrics are now saved in a JSON file.
    Analysis.py will perform calculations on the metrics to format for the server. Currently the average of each metric is calculated per punch type, per quadrant. Overall average of each metric is calcu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
2023-03-19 Updating performance calculation and result
    Performance calculation is now based on the value against the maximum in that category, instead of the average.
    Force[i] / Max(Force) + ...
    Performance has also been adjusted as a metric across all punches instead of per punch type (straight, hook, uppercut).
    The final formatting of the JSON now follows the backend that @JameTran made.
    [Analysis.py, MotorControl.py]
2023-03-20 Adjust performance calculation
    Adjust the performance calculation again.
    The normalization is still performed with the max and minimum values. The minimum however will be the lowest non-zero value.
    Rationale was that a missed punch results in a zero (or near zero) score that skews the normalized values. This approach aims to give better looking results that stay true to the purpose of the metric.
    [Analysis.py]
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2023-03-26 Updated motor pins for new wiring
    Wiring has been completed, motor and limit switch pins have been updated to reflect this.
2023-03-30 Migrating from gpiozero to RPI.GPIO for servos
    Issues seem to appear when gpiozero and RPi.GPIO are mixed. New code controls the servos with PWM using the RPi.GPIO library (same as the steppers).
    [ServoMovement.py, servo-2-test.py]
2023-04-01 Pads and gantry now work together
    The pad control servos now work together with the gantry steppers.
    Problem was the pwm.start() function was being used in the class initialization, and not carrying over to the multiprocesses (as it creates copies of the objects).
    [MotorControl.py, ServoMovement.py, StepperMovement.py]
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2023-04-07 Communication between Jetson and Pi
    The Jetson now tells the Pi when to begin movements. After the session ends, the Jetson sends the form metrics over to the Pi as well.
2023-04-08 Added form score
    Form score is now calculated from data collected by the Jetson.
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2023-04-15 adding Cad Design folder
    [Slider Top 2.stl, finger.ipt, padmount_doubleservo.iam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]
2023-04-15 bottom half of pad arm
    [stick_mount.stl]
2023-04-15 skateboard bearing housing
    [servo_pressfit_plate.stl]
2023-04-15 pitch motor mount
    [servo_horz_plate.stl]
2023-04-15 roll motor mount
    [separator_plate_alternate.stl]
2023-04-15 top of pad arm
    [finger.stl]
2023-04-15 pad control unit assembly
    [padmount_alt.stl]
2023-04-15 STL files for the gantry system
    [Carbon Rod Mount L.stl, Carbon Rod Mount R.stl, Idler Mount.stl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]
